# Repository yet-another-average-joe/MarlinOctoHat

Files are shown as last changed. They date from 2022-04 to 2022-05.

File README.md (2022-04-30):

# MarlinOctoHat
 
How to get rid of the Reprap Discount Full Graphics Smart Controller, and display Marlin on the OctoPi LCD.

The easiest and most efficient way to fetch the Marlin UI frames is to enable the MKS_12864OLED display in Configuration.h.

The MKS OLED 1.3" 128x64 Full Graphics Controller is based on the SSD1306, a very common OLED module. This display basically is an SPI slave. But the RaspBerry Foundation didn't think or didn't want to enable/support the SPI slave mode, which is required for emulation....

The Marlin graphics driver (a optimized u8glib fork) sends bitmaps @1Mbps. The STM32 BluePill gets these frames, reencodes them, and makes them available to the RaspBerry Pi SPI master interface. When a new frame is ready, the STM32 sends a pulse to the RasPi. The RasPi then reads the STM32 at up to 28Mbps (adjustable in the OctoPrint plugin).

As a result, the printer motherboard "sees" a SSD1306 SPI slave, and the RasPi "sees" the printer motherboard as a SPI slave peripheral ! Thanks to the STM32F103 dual SPI, and to the developpers that implemented the SPI DMA mode in the Roger's core !

The RaspBerry runs a service that overlays the Marlin UI onto the RaspBerry display using dispmanx, and an OctoPrint plugin allows for easy display customization.

This repo contains everything needed to build the hat (two PCBs and a firmware) that replaces the 12864 display. The hat is connected to the printer motherboard through the EXP1 and EXP2 connectors, and breaks out the rotary encoder, the reset button for the STM32 and the motherboard, the speaker, the "Marlin Mode" button, and a 5V screw terminal to for the RasPi and the STM32 power. It also breaks out the RasPi UART for direct connection to the motherboard (if supported...). Both 3.3V and 5V printer motherboards are supported.

The two PCBs are inexpensive, easy to populate using a decent soldering iron, and require components that every tinkerer has at hand (through hole only) : a BluePill (legit or fake), a couple of NPN tranistors and resistors, a small diode, 4 jumpers and some pinheaders and sockets (including a long RaspBerry 2x20 PC104-style pin header/socket). Everything can be easily sourced from Amazon, eBay, Ali...

The KiCad projects and the Gerber files are provided. Just order the PCBs from a manufacturer (JLCPCB, PCBWay, etc.)

Hat firmware : see https://github.com/yet-another-average-joe/MarlinOctoHat/tree/main/MarlinOctoHat_Firmware

RasPi software (service and OctoPrint plugin) :

service : https://github.com/yet-another-average-joe/OctoPrint_MarlinOSD_Service

plugin : https://github.com/yet-another-average-joe/OctoPrint_MarlinOSD_Plugin

**The SSD1306 (MKS OLED 1.3" 128x64 Full Graphics Controller) is not supported for all motherboards, even though the option is available in Configuration.h ; enabling support is not difficult, but requires sone basic knowledge about Marlin and microcontrollers ! The pins files are somewhere under Marlin/src/pins : some "#define..." to add if needed. The motherboard schematics and pinouts might be needed ; forums and dicussion groups could be helpfull !**

First, enable the "MKS OLED 1.3" 128x64 Full Graphics Controller" in Configurattion.h :

#define MKS_12864OLED

If the OLED is not supported, you will get a compile error similar to :

In file included from Marlin\src\lcd\dogm\marlinui_DOGM.cpp:42:

Marlin\src\lcd\dogm\marlinui_DOGM.cpp: In static member function 'static void MarlinUI::init_lcd()':

Marlin\src\lcd\dogm\marlinui_DOGM.h:223:48: error: 'DOGLCD_CS' was not declared in this scope; did you mean 'DOGLCD_SCK'?

You'll have to add such a block in your pins definition file :

      #elif ENABLED(MKS_12864OLED_SSD1306)
        #define DOGLCD_CS            EXP1_05_PIN
        #define DOGLCD_A0            EXP1_04_PIN
        #define DOGLCD_SCK           EXP2_09_PIN
        #define DOGLCD_MOSI          EXP2_05_PIN
        #define LCD_PINS_DC          LCD_PINS_D4
        //#define FORCE_SOFT_SPI                      // Use this if default of hardware SPI causes display problems
      #endif

You could have to figure wich microcontroller pins go to the EXP1 and EXP2 pin headers. May be done without the schematics, but easier with.

**THIS IS AN EXAMPLE !** : lines I had to add to /Marlin/src/pins/lpc1768/pins_BTT_SKR_V1_4.h for a SKR 1.4 Turbo.

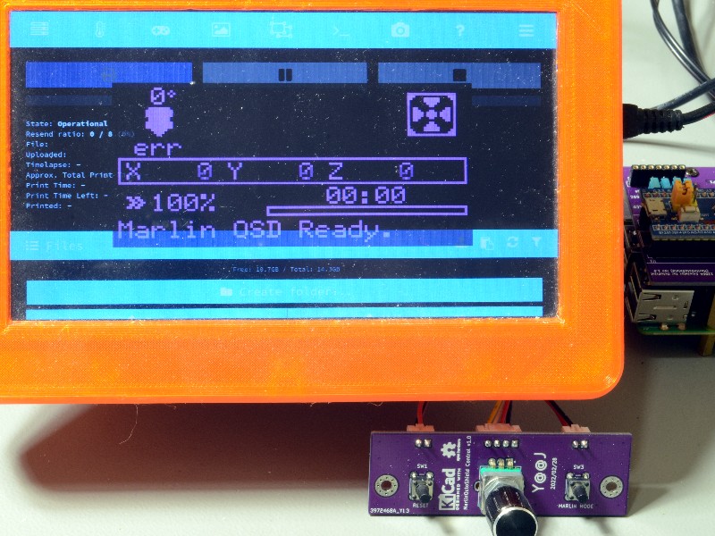
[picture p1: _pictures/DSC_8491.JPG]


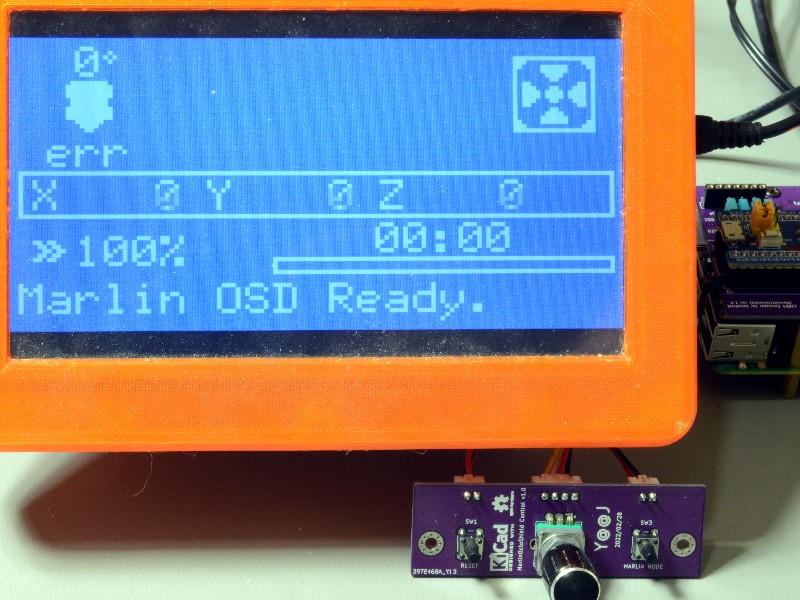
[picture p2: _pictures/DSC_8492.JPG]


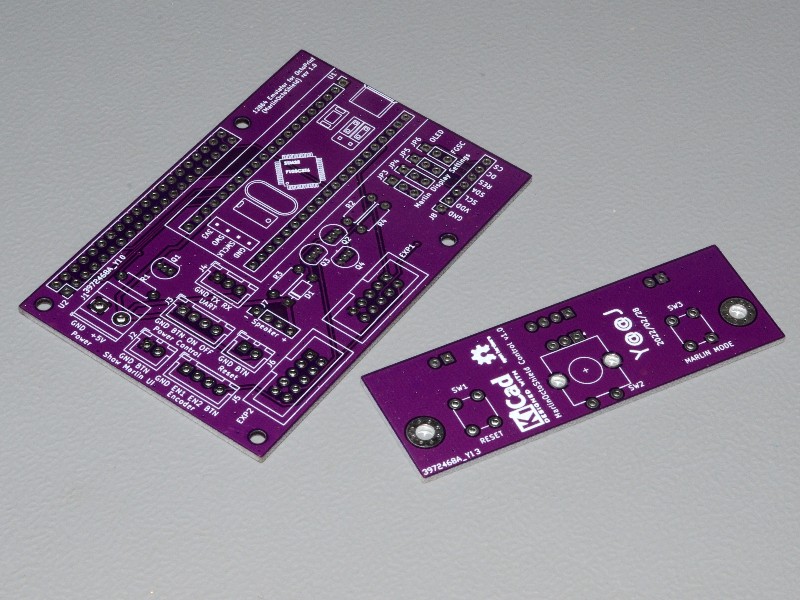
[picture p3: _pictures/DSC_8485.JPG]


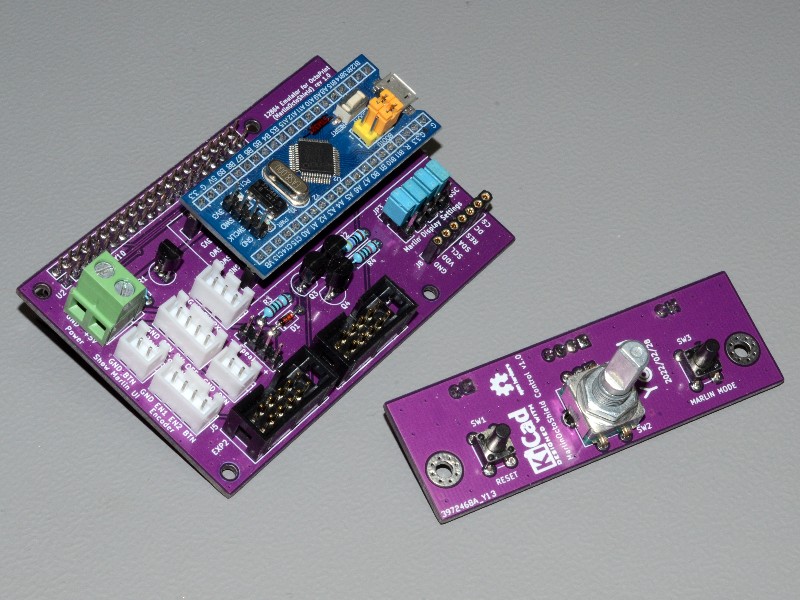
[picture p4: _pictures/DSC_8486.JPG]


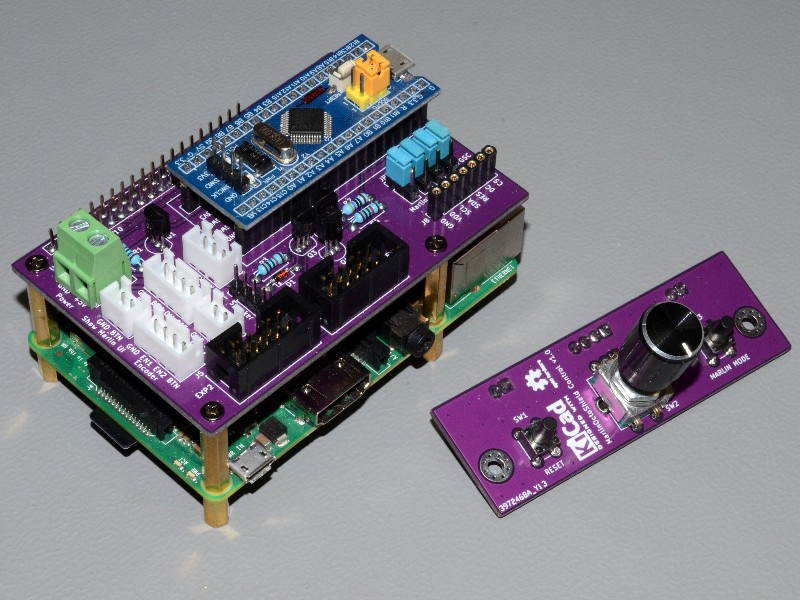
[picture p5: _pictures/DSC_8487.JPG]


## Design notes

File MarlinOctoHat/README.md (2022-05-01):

# MarlinOctoHat : hat PCB
 
The Blue Pill may be legit or "fake" : tested with ST Microeletronics STM32F103C8 and chinese CKS32F103C8T6.

**KiCad 6.0 project** :

subfolders :

- **bom** : bill of material created with "Interactive Html Bom" plugin
- **fabrication** : fabrication files created with "KiCAD JLCPCB tools" plugin

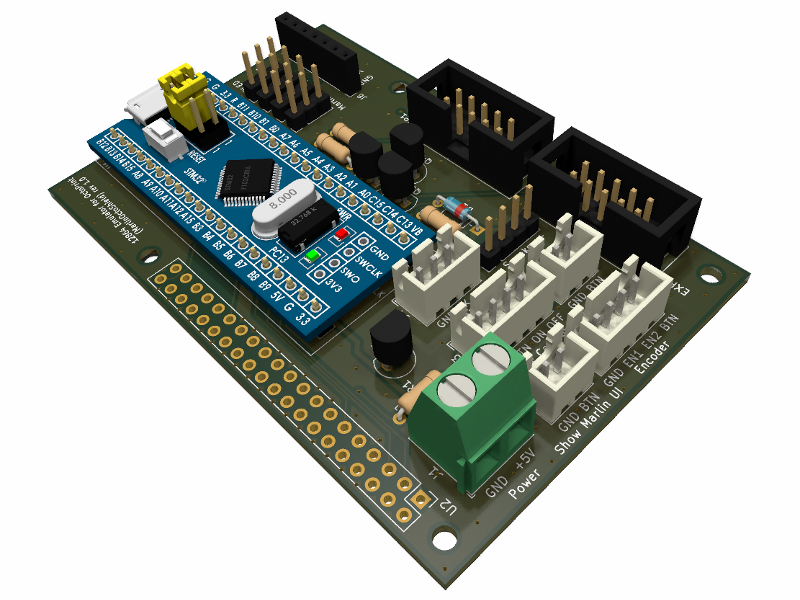
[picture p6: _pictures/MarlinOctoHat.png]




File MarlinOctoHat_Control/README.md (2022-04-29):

# MarlinOctoHat_Control : control board
 
**KiCad 6.0 project** :

subfolders :

- **bom** : bill of material created with "Interactive Html Bom" plugin
- **fabrication** : fabrication files created with "KiCAD JLCPCB tools" plugin

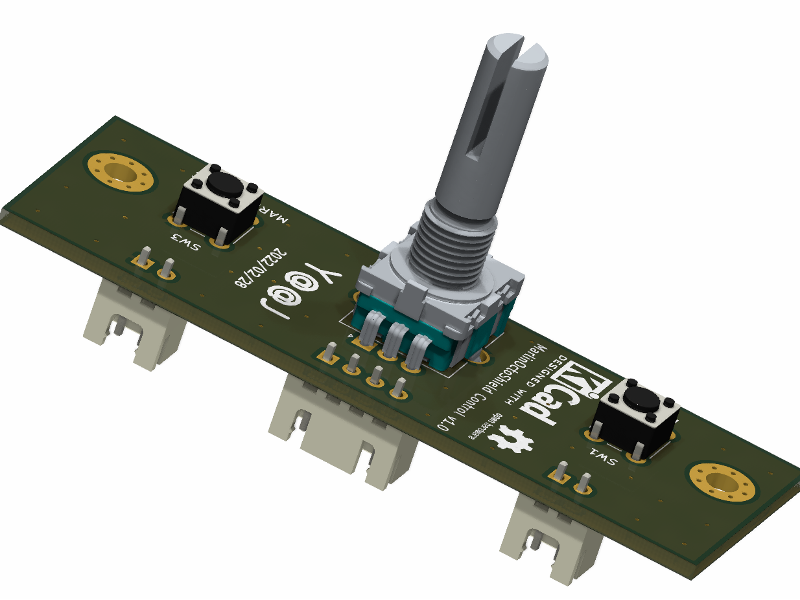
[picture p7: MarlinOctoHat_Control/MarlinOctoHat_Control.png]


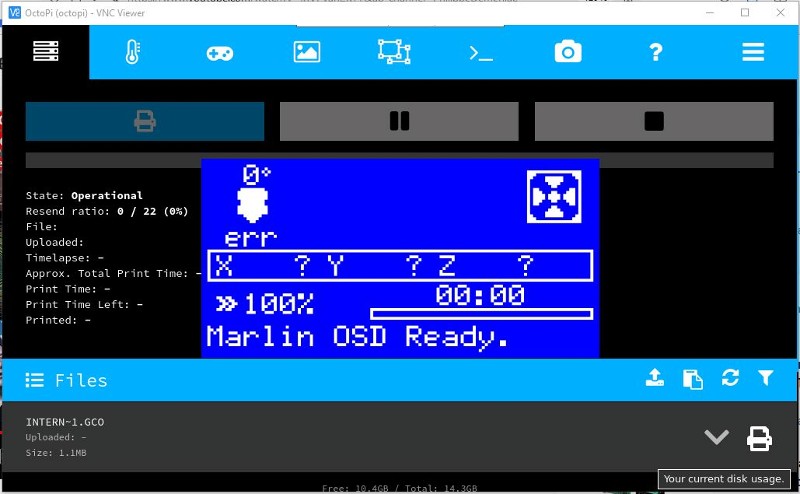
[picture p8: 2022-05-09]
_pictures/VNC_Capture_01.JPG

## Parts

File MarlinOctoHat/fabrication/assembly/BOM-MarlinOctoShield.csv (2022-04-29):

Comment | Designator | Footprint | LCSC
BC547 | Q3 | TO-92_Inline
Jumper_3_Bridged12 | JP6 | PinHeader_1x03_P2.54mm_Vertical
10k | R1 | R_Axial_DIN0207_L6.3mm_D2.5mm_P7.62mm_Horizontal
BC547 | Q4 | TO-92_Inline
MountingHole | H1 | MountingHole_2.7mm_M2.5_DIN965
MountingHole | H4 | MountingHole_2.7mm_M2.5_DIN965
Conn_01x02_Male | J2 | JST_KNOCKOFF_XH_B2B-XH-A_1x02_P2.54mm_Vertical
Jumper_2_Open | JP3 | PinHeader_1x03_P2.54mm_Vertical
Jumper_3_Bridged12 | JP4 | PinHeader_1x03_P2.54mm_Vertical
Conn_01x02_Male | J6 | JST_KNOCKOFF_XH_B2B-XH-A_1x02_P2.54mm_Vertical
Conn_01x07_Female | J8 | PinSocket_1x07_P2.54mm_Vertical
MountingHole | H2 | MountingHole_2.7mm_M2.5_DIN965
YAAJ_BluePill_Part_Like | U1 | YAAJ_BluePill_1
Conn_02x05_Odd_Even | EXP1 | IDC-Header_2x05_P2.54mm_Vertical
Conn_01x04_Male | J3 | JST_KNOCKOFF_XH_B4B-XH-A_1x04_P2.54mm_Vertical
Conn_01x03_Male | J4 | JST_KNOCKOFF_XH_B3B-XH-A_1x03_P2.54mm_Vertical
BC547 | Q2 | TO-92_Inline
Screw_Terminal_01x03 | J1 | TerminalBlock_Phoenix_MKDS-1,5-2-5.08_1x02_P5.08mm_Horizontal
1N4148 | D1 | D_DO-35_SOD27_P7.62mm_Horizontal
Jumper_3_Bridged12 | JP5 | PinHeader_1x03_P2.54mm_Vertical
MountingHole | H3 | MountingHole_2.7mm_M2.5_DIN965
10k | R4 | R_Axial_DIN0207_L6.3mm_D2.5mm_P7.62mm_Horizontal
Conn_02x05_Odd_Even | EXP2 | IDC-Header_2x05_P2.54mm_Vertical
10k | R3 | R_Axial_DIN0207_L6.3mm_D2.5mm_P7.62mm_Horizontal
Conn_01x02_Male | J7 | PinHeader_1x04_P2.54mm_Vertical
Conn_01x04_Male | J5 | JST_KNOCKOFF_XH_B4B-XH-A_1x04_P2.54mm_Vertical
YAAJ_Raspberry_Pi_2_3_GPIO | U2 | PinHeader_2x20_P2.54mm_Vertical
470 | R2 | R_Axial_DIN0207_L6.3mm_D2.5mm_P7.62mm_Horizontal
BC547 | Q1 | TO-92_Inline

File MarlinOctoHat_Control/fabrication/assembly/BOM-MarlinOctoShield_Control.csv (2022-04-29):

Comment | Designator | Footprint | LCSC
SW_Push | SW1 | SW_PUSH_6mm_H4.3mm_Orig_Center
MountingHole | H2 | MountingHole_3.2mm_M3_Pad_Via
MountingHole | H1 | MountingHole_3.2mm_M3_Pad_Via
RotaryEncoder_Switch | SW2 | RotaryEncoder_Alps_EC11E-Switch_Vertical_H20mm_CircularMountingHoles_Orig_Center
3 | SW3 | SW_PUSH_6mm_H4.3mm_Orig_Center
Conn_01x02_Male | J3 | JST_KNOCKOFF_XH_B2B-XH-A_1x02_P2.54mm_Vertical
Conn_01x04_Male | J2 | JST_KNOCKOFF_XH_B4B-XH-A_1x04_P2.54mm_Vertical
Conn_01x02_Male | J1 | JST_KNOCKOFF_XH_B2B-XH-A_1x02_P2.54mm_Vertical

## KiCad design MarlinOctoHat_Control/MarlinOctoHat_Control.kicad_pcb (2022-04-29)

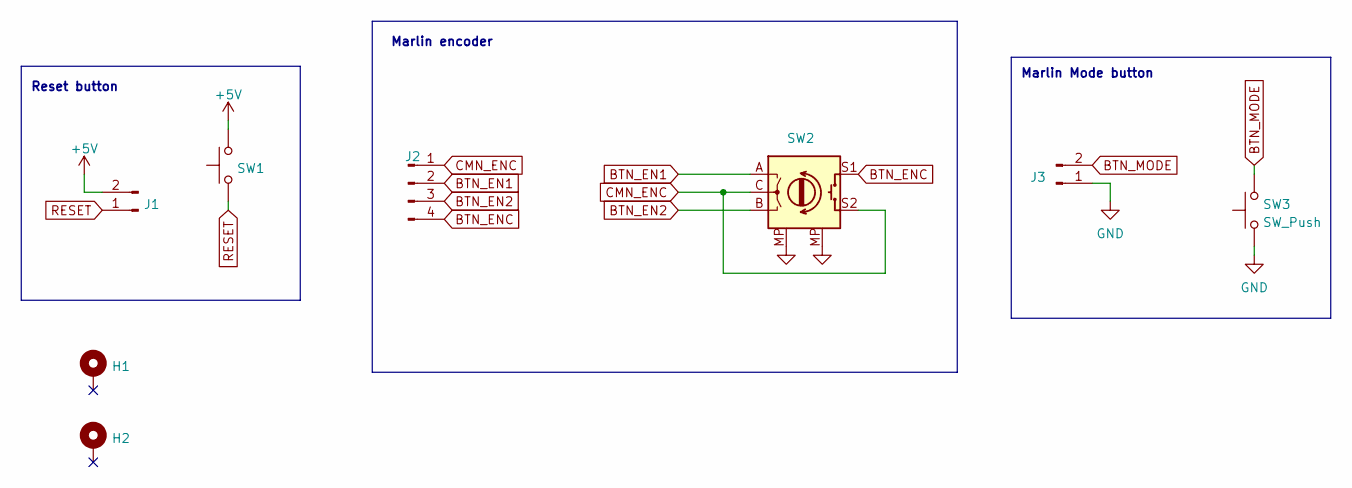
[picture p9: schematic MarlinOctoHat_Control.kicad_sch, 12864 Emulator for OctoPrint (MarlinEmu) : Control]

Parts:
H1, H2: MountingHole; MountingHole_3.2mm_M3_Pad_Via
J1, J3: Conn_01x02_Male; JST_KNOCKOFF_XH_B2B-XH-A_1x02_P2.54mm_Vertical
J2: Conn_01x04_Male; JST_KNOCKOFF_XH_B4B-XH-A_1x04_P2.54mm_Vertical
SW1, SW3: SW_Push; SW_PUSH_6mm_H4.3mm_Orig_Center
SW2: RotaryEncoder_Switch; RotaryEncoder_Alps_EC11E-Switch_Vertical_H20mm_CircularMoun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

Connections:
+5V: J1.2, SW1.2
BTN_EN1: J2.2, SW2.A
BTN_EN2: J2.3, SW2.B
BTN_ENC: J2.4, SW2.S1
BTN_MODE: J3.2, SW3.2
CMN_ENC: J2.1, SW2.C, SW2.S2
GND: J3.1, SW2.MP, SW3.1
RESET: J1.1, SW1.1

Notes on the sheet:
Marlin Mode button
Reset button
Marlin encoder

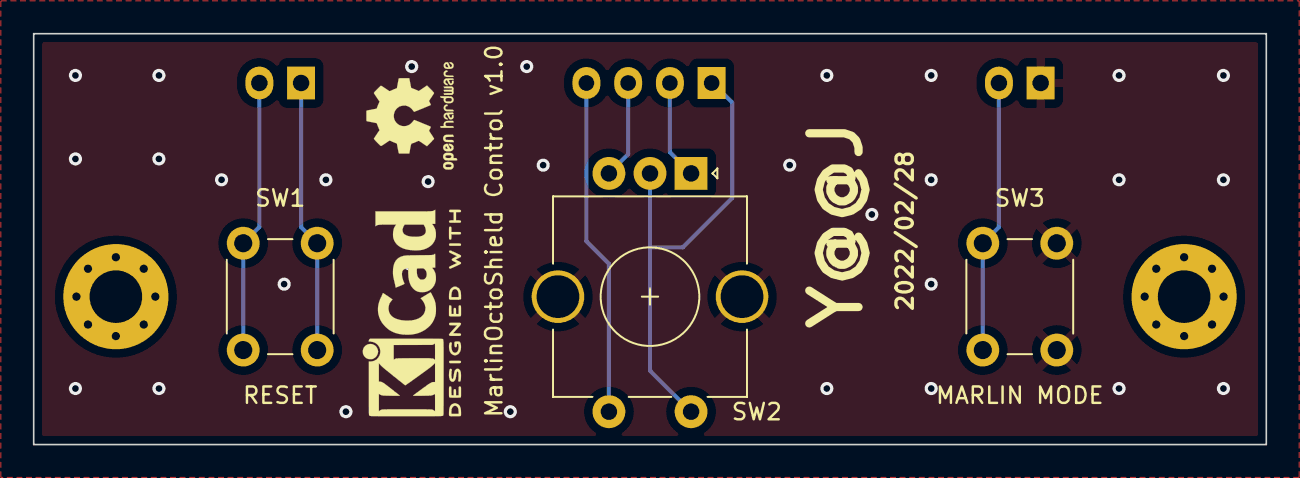
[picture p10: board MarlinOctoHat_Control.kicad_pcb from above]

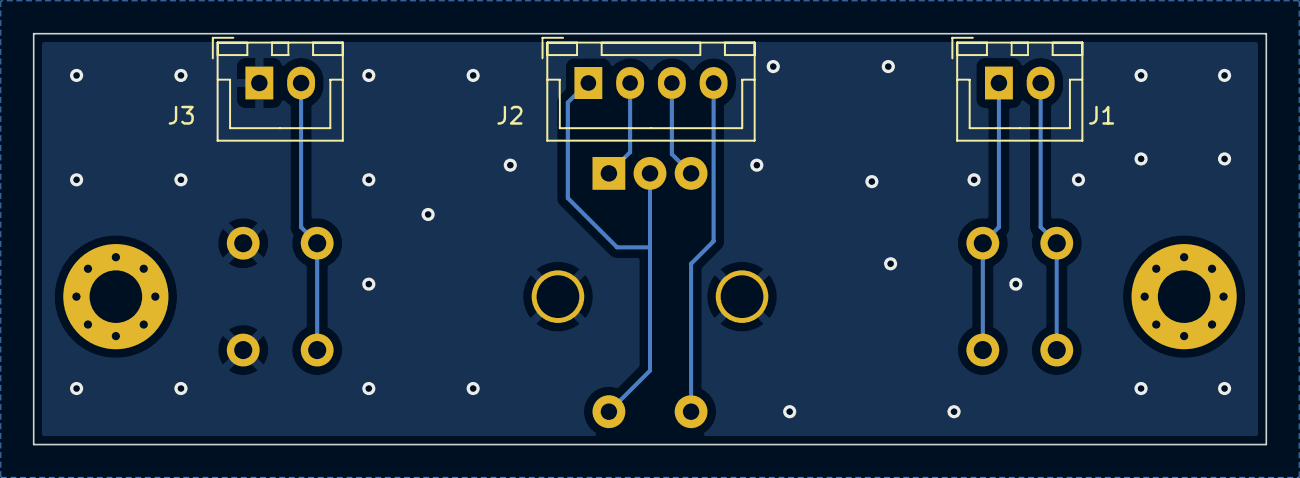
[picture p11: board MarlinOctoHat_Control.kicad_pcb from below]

Board: 2 copper layers, 75.0 x 25.0 mm, 8 parts (3 on the bottom side), 8 nets.

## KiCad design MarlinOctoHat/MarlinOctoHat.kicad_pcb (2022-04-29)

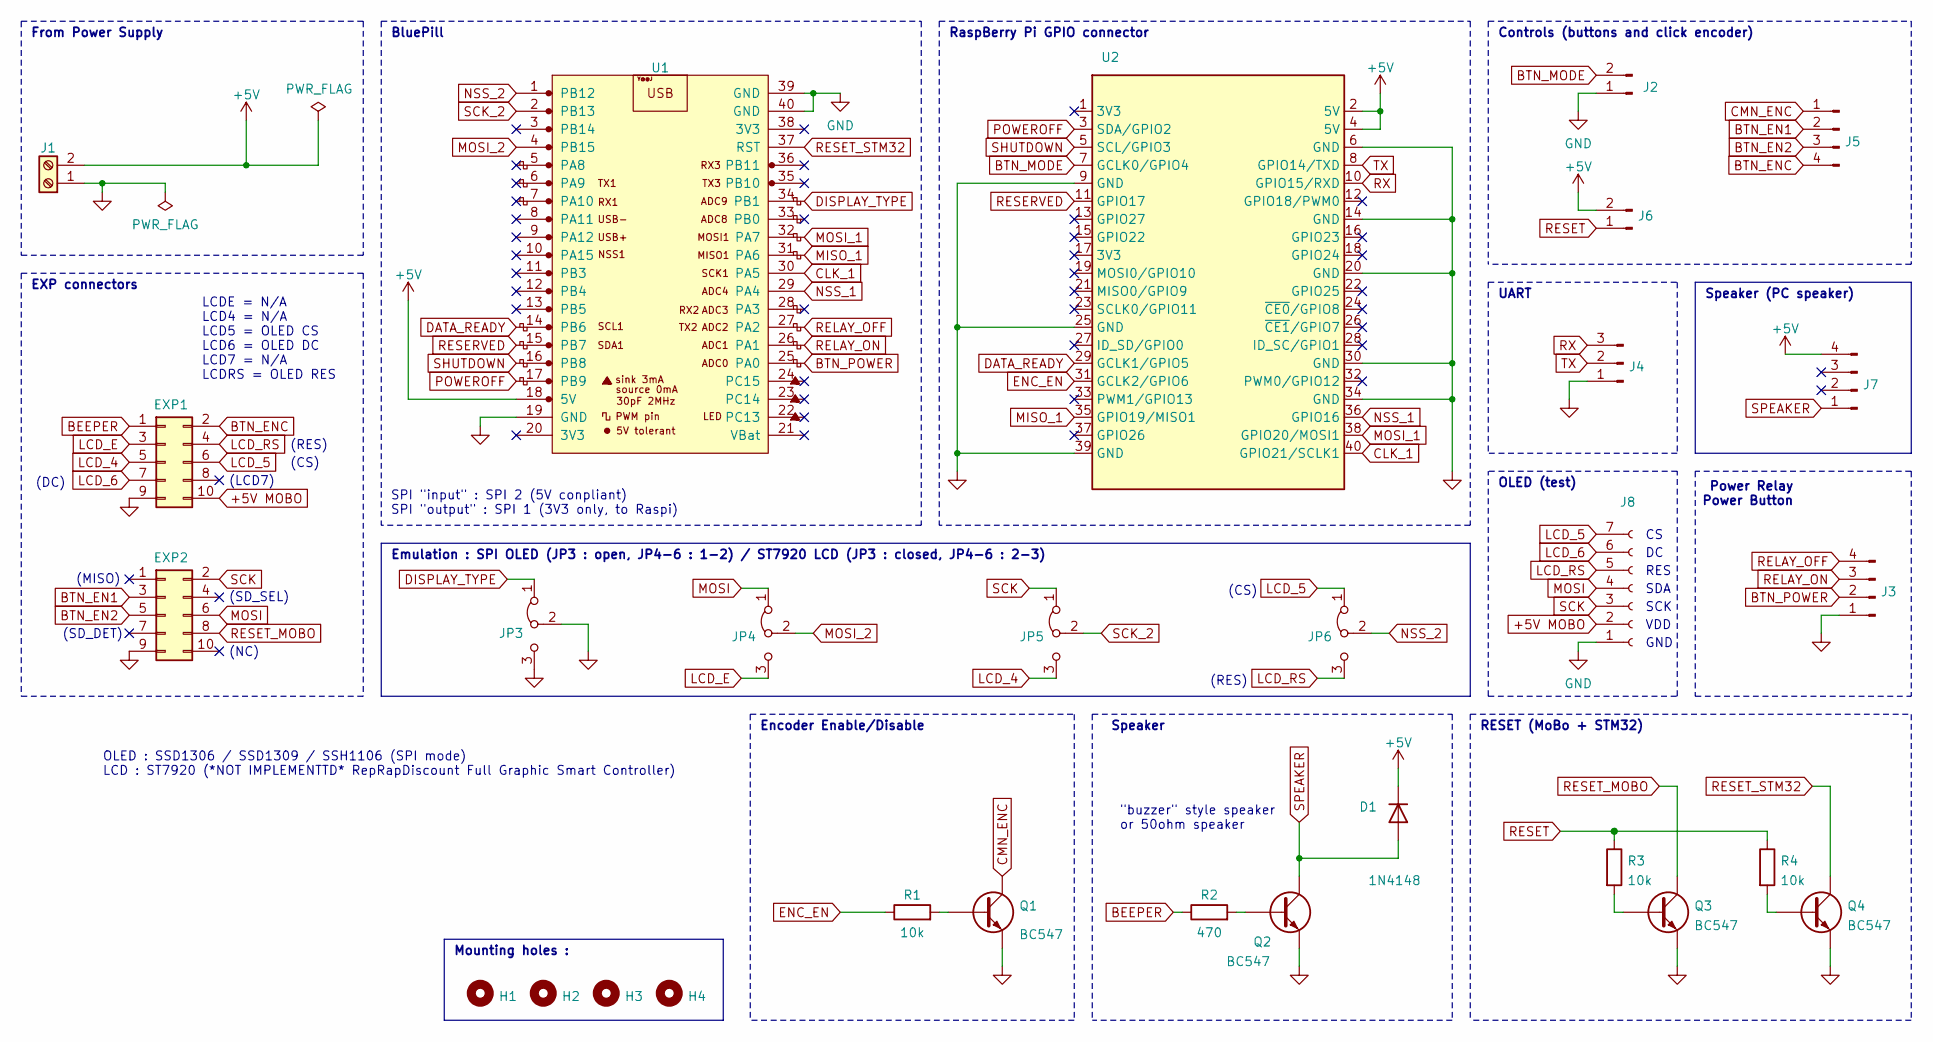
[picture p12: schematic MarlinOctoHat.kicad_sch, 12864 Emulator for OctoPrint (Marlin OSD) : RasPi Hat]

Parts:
D1: 1N4148; D_DO-35_SOD27_P7.62mm_Horizontal
EXP1, EXP2: Conn_02x05_Odd_Even; IDC-Header_2x05_P2.54mm_Vertical
H1, H2, H3, H4: MountingHole; MountingHole_2.7mm_M2.5_DIN965
J1: Screw_Terminal_01x03; TerminalBlock_Phoenix_MKDS-1,5-2-5.08_1x02_P5.08mm_Horizont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
J2, J6: Conn_01x02_Male; JST_KNOCKOFF_XH_B2B-XH-A_1x02_P2.54mm_Vertical
J3, J5: Conn_01x04_Male; JST_KNOCKOFF_XH_B4B-XH-A_1x04_P2.54mm_Vertical
J4: Conn_01x03_Male; JST_KNOCKOFF_XH_B3B-XH-A_1x03_P2.54mm_Vertical
J7: Conn_01x04_Male; PinHeader_1x04_P2.54mm_Vertical
J8: Conn_01x07_Female; PinSocket_1x07_P2.54mm_Vertical
JP3: Jumper_2_Open; PinHeader_1x03_P2.54mm_Vertical
JP4, JP5, JP6: Jumper_3_Bridged12; PinHeader_1x03_P2.54mm_Vertical
Q1, Q2, Q3, Q4: BC547; TO-92_Inline
R1, R3, R4: 10k; R_Axial_DIN0207_L6.3mm_D2.5mm_P7.62mm_Horizontal
R2: 470; R_Axial_DIN0207_L6.3mm_D2.5mm_P7.62mm_Horizontal
U1: YAAJ_BluePill_Part_Like; YAAJ_BluePill_1
U2: YAAJ_Raspberry_Pi_2_3_GPIO; PinHeader_2x20_P2.54mm_Vertical

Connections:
+5V: D1.1 (K), J1.2, J6.2, J7.4, U1.18 (5V), U2.2 (5V), U2.4 (5V)
+5V MOBO: EXP1.10, J8.2
BEEPER: EXP1.1, R2.1
BTN_EN1: EXP2.3, J5.2
BTN_EN2: EXP2.5, J5.3
BTN_ENC: EXP1.2, J5.4
BTN_MODE: J2.2, U2.7 (GCLK0/GPIO4)
BTN_POWER: J3.2, U1.25 (PA0)
CLK_1: U1.30 (PA5), U2.40 (GPIO21/SCLK1)
CMN_ENC: J5.1, Q1.1 (C)
DATA_READY: U1.14 (PB6), U2.29 (GCLK1/GPIO5)
DISPLAY_TYPE: JP3.1 (A), U1.34 (PB1)
ENC_EN: R1.1, U2.31 (GCLK2/GPIO6)
GND: EXP1.9, EXP2.9, J1.1, J2.1, J3.1, J4.1, J8.1, JP3.2 (C), JP3.3 (B), Q1.3 (E), Q2.3 (E), Q3.3 (E), Q4.3 (E), U1.19 (GND), U1.39 (GND), U1.40 (GND), U2.6 (GND), U2.9 (GND), U2.14 (GND), U2.20 (GND), U2.25 (GND), U2.30 (GND), U2.34 (GND), U2.39 (GND)
LCD_4: EXP1.5, JP5.3 (B)
LCD_5: EXP1.6, J8.7, JP6.1 (A)
LCD_6: EXP1.7, J8.6
LCD_E: EXP1.3, JP4.3 (B)
LCD_RS: EXP1.4, J8.5, JP6.3 (B)
MISO_1: U1.31 (PA6), U2.35 (GPIO19/MISO1)
MOSI: EXP2.6, J8.4, JP4.1 (A)
MOSI_1: U1.32 (PA7), U2.38 (GPIO20/MOSI1)
MOSI_2: JP4.2 (C), U1.4 (PB15)
NSS_1: U1.29 (PA4), U2.36 (GPIO16)
NSS_2: JP6.2 (C), U1.1 (PB12)
unnamed: Q1.2 (B), R1.2
unnamed: Q2.2 (B), R2.2
unnamed: Q3.2 (B), R3.2
unnamed: Q4.2 (B), R4.2
POWEROFF: U1.17 (PB9), U2.3 (SDA/GPIO2)
RELAY_OFF: J3.4, U1.27 (PA2)
RELAY_ON: J3.3, U1.26 (PA1)
RESERVED: U1.15 (PB7), U2.11 (GPIO17)
RESET: J6.1, R3.1, R4.1
RESET_MOBO: EXP2.8, Q3.1 (C)
RESET_STM32: Q4.1 (C), U1.37 (RST)
RX: J4.3, U2.10 (GPIO15/RXD)
SCK: EXP2.2, J8.3, JP5.1 (A)
SCK_2: JP5.2 (C), U1.2 (PB13)
SHUTDOWN: U1.16 (PB8), U2.5 (SCL/GPIO3)
SPEAKER: D1.2 (A), J7.1, Q2.1 (C)
TX: J4.2, U2.8 (GPIO14/TXD)

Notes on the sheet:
OLED (test)
SCK
(LCD7)
OLED : SSD1306 / SSD1309 / SSH1106 (SPI mode) LCD : ST7920 (*NOT IMPLEMENTTD* RepRapDiscount Full Graphic Smart Controller)
RaspBerry Pi GPIO connector
Emulation : SPI OLED (JP3 : open, JP4-6 : 1-2) / ST7920 LCD (JP3 : closed, JP4-6 : 2-3)
(NC)
(CS)
GND
UART
BluePill
(SD_SEL)
RESET (MoBo + STM32)
(DC)
From Power Supply
Speaker (PC speaker)
Mounting holes :
(SD_DET)
RES
VDD
SDA
SPI "input" : SPI 2 (5V conpliant) SPI "output" : SPI 1 (3V3 only, to Raspi)
"buzzer" style speaker or 50ohm speaker
(RES)
Speaker
Encoder Enable/Disable
EXP connectors
Power Relay Power Button
(MISO)
Controls (buttons and click encoder)
LCDE = N/A LCD4 = N/A LCD5 = OLED CS LCD6 = OLED DC LCD7 = N/A LCDRS = OLED RES

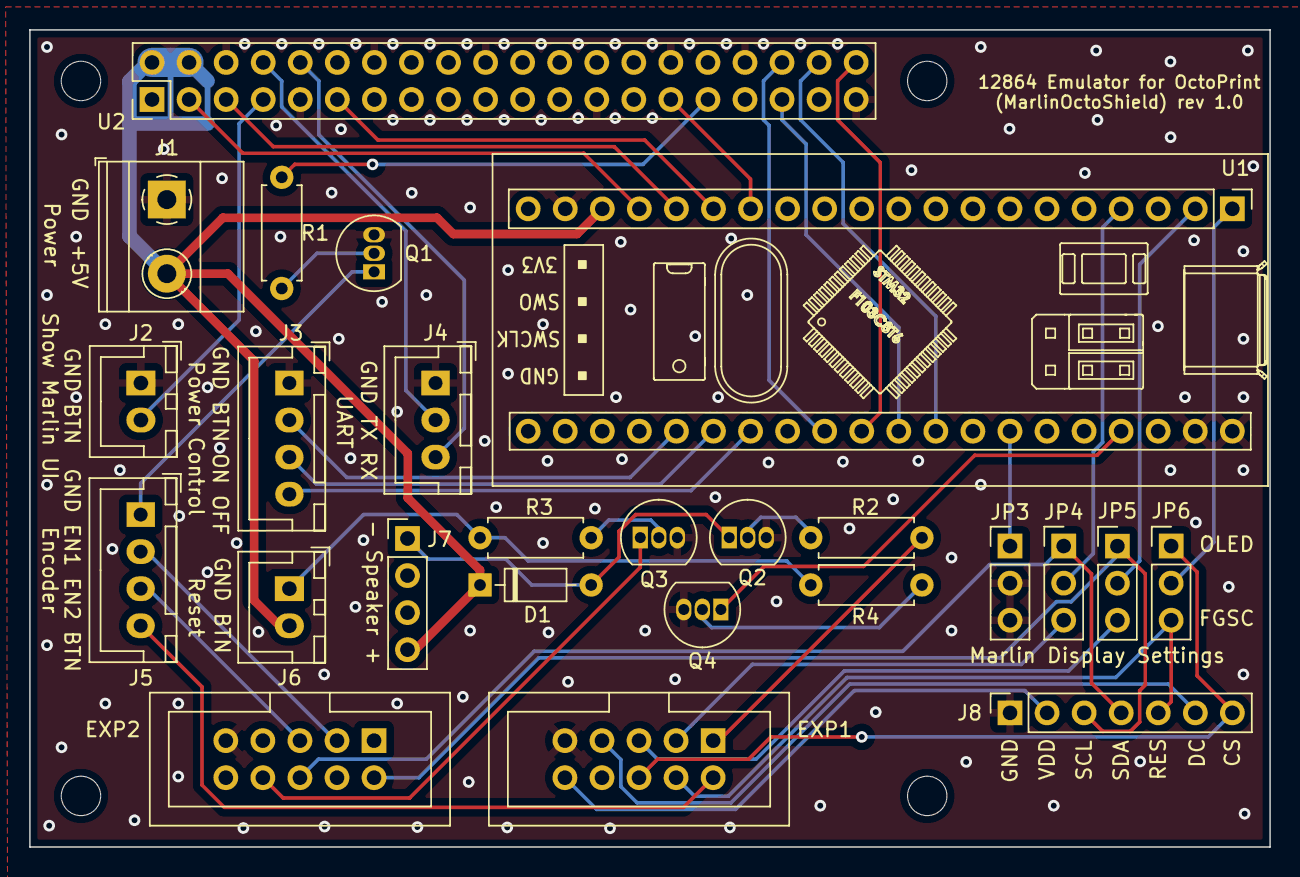
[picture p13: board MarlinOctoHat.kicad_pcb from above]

Board: 2 copper layers, 85.0 x 56.0 mm, 30 parts (1 on the bottom side), 42 nets.

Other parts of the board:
LOGO1: OSHW-Logo_7.5x8mm_SilkScreen

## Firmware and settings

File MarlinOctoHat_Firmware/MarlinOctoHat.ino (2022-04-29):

/*
 Name:        MarlinOctoHat.ino
 Created:    31/08/2021 11:16:18
 Author:    Y@@J
    TODO : pins PB10/PB11 = input for emulator selection OLED SSD1306 / OLED SSD1309 / OLED SSH1106 / LCD ST7920
            DISPLAY_TYPE : PB1
    TODO : power management
            support for monostable relay throught PIN_RELAY_ON
    /////////////////////////////////////////////////////////////////////////////////////
    SPI Slave Sniffer for the SSD1306/SSD1309/SSH1106 OLED ; for marlin UI, u8glib
    tested Ok with SPI SSD1309 OLED and Marlin v2.0.x on genuine and fake STM32F103C6 ("BluePill")
    /////////////////////////////////////////////////////////////////////////////////////
    thread on stm32duino.com, and special thanks for the help about SPI DMA tranfers ! :
    https://www.stm32duino.com/viewtopic.php?t=825
    SSD1306 datasheet :
    https://cdn-shop.adafruit.com/datasheets/SSD1306.pdf
    SPI data :
    1 SPI frame = 8 pages
    1 page = 8lines/128 pixels, vertical macropixels
    1 page : 3 command bytes + 128 bytes (= 8 lines on the display)
    1 command byte = 0x10 0x00 0XBn , n = page # (0...7)
    total : 8 pages ; 8 * 131 = 1048 bytes, CLK @ 1MHz
    /////////////////////////////////////////////////////////////////////////////////////
    // OLED wirings
        SSD1306-9        SPI
        SH1106
        SCL                SCLK
        SDA                MOSI
        RES                N/A
        DC                N/A
        SS                SS
    SS : LOW for pages, including commands ; HIGH between pages and between frames
    DC : LOW for commands only
    // BluePill / RaspBerry Pi wirings
                                              ----------
                        (LCD_5)  [NSS2] PB12 |            | GND
                        (SCK)    [SCK2] PB13 |            | GND
                                        PB14 |            | 3V3
                        (MOSI)  [MOSI2] PB15 |            | RESET
                                         PA8 |            | PB11 -> GPIO2  (AUX4)
                                         PA9 |            | PB10 -> GPIO3  (AUX3)
                                        PA10 |            | PB1
                                        PA11 |            | PB0
                                        PA12 |            | PA7  [MOSI1] -> GPIO20 (SPI1 MOSI)
                                        PA15 |            | PA6  [MISO1] -> GPIO19 (SPI1 MISO)
                             (LCD_E)    PB3  |            | PA5  [SCK1]  -> GPIO21 (SPI1 SCLK)
                             (LCD_4)    PB4  |            | PA4  [NSS1]  -> GPIO16 (SPI1 CS0)
                             (LCD_7)    PB5  |            | PA3
        GPIO5  <- DATA_READY            PB6  |            | PA2  PIN_RELAY_OFF
        GPIO17 <- PIN_SOFT_SHUTDOWN     PB7  |            | PA1  PIN_RELAY_ON
        GPIO3  <- PIN_HARD_SHUTDOWN     PB8  |            | PA0  PIN_BTN_POWER
        GPIO2  <- PIN_POWEROFF          PB9  |            | PC15
                                         5V  |            | PC14
                                        GND  |            | PC13
                                        3V3  |            | VBAT
                                             |            |
                                              ----------
    LCD_E, LCD_4, LCD_7 : variant with ST7920 emulator (not implemented)
    SPI2 : SPI "input" (MOSI), from printer motherboard
    ---------------------------------------------------
        STM32 Pins : 5V tolerant
            MoBo        OLED    BluePill
            XP1_5        CS        PB12    PIN_SS_2
            XP2-9        SCL       PB13    PIN_SCK_2
                         N/C       PB14
            EXP2-5       SDA       PB15    PIN_MOSI_2
    SPI1 :    SPI "output" (MISO), to RasPi
    -------------------------------------
        STM32 Pins : /!\ NOT 5V TOLERANT /!\
            PIN_READY : high for READY_PULSE_DURATION ms when a new bitmap is available
                        tells the RasPi it's time to get data and refresh display
                        drastically reduces RasPi CPU usage
                    BluePill            PasPi
             PA7    PIN_MOSI1            [38]    GPIO20    MOSI1
            (PA6    PIN_MISO1            [35]    GPIO19    MISO1)
             PA5    PIN_SCK1             [40]    GPIO21    SCK1
             PA4    PIN_NSS1             [36]    GPIO16    NSS1
             PB6    PIN_READY            [29]    GPIO5     data ready to send
             PB7    PIN_SOFT_SHUTDOWN    [11]    GPIO17    output, default = LOW, HIGH = short press -> OctoPrint Shutdown
             PB8    PIN_HARD_SHUTDOWN    [5]     GPIO3     output, default = LOW, HIGH triggered by PIN_BTN_POWER long press -> OS Shutdown
             PB9    PIN_POWEROFF         [3]     GPIO2     input, interrupt
             PA0    PIN_BTN_POWER        [33]    GPIO13    input, pullup,    interrupt, sends 1 sec LOW pulse to PIN_HARD_SHUTDOWN
             PA1    PIN_RELAY_ON         [32]    GPIO12    output, default = LOW, HIGH for 1 sec at boot
             PA2    PIN_RELAY_OFF        [31]    GPIO6     output, default = LOW, HIGH triggerd by PIN_POWEROFF

*/
lkjhsqdgfklhjgbqskdhjgbksdqjhgdksjhkqgqsdkjfhgqsdf
#include <SPI.h>
//#include "Bitmaps.h"

//#define __SERIAL_DEBUG // costs 2328 bytes

//////////////////////////////////////////////////////////////////////////////////////////////////////////////
// pins : pullups ? pulldowns ?

// SPI_1 : input (MOSI), OLED sniffing ; /!\ *NOT* 5V tolerant
// SPI_2 : output (MISO), to RaspBerry Pi
// pins are set by the library

#define READY_PULSE_DURATION    1        // 1ms

#define PIN_READY        PB6

//#define PIN_HARD_SHUTDOWN    PB8        // to RasPi Shutdown pin (5 / GPIO3)
//#define PIN_POWEROFF         PB9        // from RasPi PowerOff pin (2 / GPIO2)
#define PIN_BTN_POWER        PA0        // Power button
#define PIN_RELAY_ON         PA1        // to PSU module ; ON bistable coil
#define PIN_RELAY_OFF        PA2        // to PSU module ; OFF bistable coil
#define PIN_SOFT_SHUTDOWN    PB7        // to RasPi (11 / GPIO17)

#define LONG_PRESS_TIME            1500    // milliseconds
#define DEBOUNCE_TIME                25    // milliseconds
#define HARD_SHUTDOWN_PULSE         500    // 100ms debounce by default on RasPi ; min pulse width 210ms (measured)
#define SOFT_SHUTDOWN_PULSE         500    // milliseconds
#define RELAY_PULSE                 500    // milliesconds ; Schrack RT314F12 : min 30 ms

//////////////////////////////////////////////////////////////////////////////////////////////////////////////
// OLED    data

// data (SSD1306/SSD1309) : 1 frame = 8 pages, 1 page = 3 command bytes + 128 bytes, 1 page = 8 graphic lines
#define OLED_PAGE_COUNT          8
#define    OLED_LINES_PER_PAGE   8
#define OLED_CMD_SIZE            3
#define OLED_PAGE_SIZE           128
#define OLED_SPI_PAGE_SIZE       (OLED_CMD_SIZE + OLED_PAGE_SIZE)        // 1048
#define OLED_SPI_FRAME_SIZE      (OLED_PAGE_COUNT * OLED_SPI_PAGE_SIZE)  // 1024

// bmpOled with vertical 8bit monochrome macropixels...
volatile uint8_t bmpOled[OLED_PAGE_COUNT][OLED_PAGE_SIZE] = { 0 };

// converts bmpOled to horizontal 8bit monochrome macropixels
// will be used as Tx buffer for SPI_1
// allways keeps the last captured screen until a new one arrives
volatile uint8_t bmpOut[OLED_PAGE_COUNT * OLED_PAGE_SIZE] = { 0 };

//////////////////////////////////////////////////////////////////////////////////////////////////////////////
// SPI 1&2 : DMA channels

#define SPI_1_TX_DMA_CH        DMA_CH3
#define SPI_2_RX_DMA_CH        DMA_CH4

//////////////////////////////////////////////////////////////////////////////////////////////////////////////
// SPI_2  : MOSI (Rx) only

SPIClass SPI_2(2);

#define PIN_NSS_2    PB12

volatile uint8_t SPI_2_Rx_Buffer[OLED_SPI_FRAME_SIZE] = { 0 };
volatile bool SPI_2_DMA_transfer_complete = false;
volatile bool SPI_2_DMA_error = false;

// DMA tube configuration for SPI2 Rx
dma_tube_config SPI_2_DMA_RxTubeCfg =
{
    &SPI2->regs->DR,           // Source of data
    DMA_SIZE_8BITS,            // Source transfer size
    &SPI_2_Rx_Buffer,          // Destination of data
    DMA_SIZE_8BITS,            // Destination transfer size
    sizeof(SPI_2_Rx_Buffer),   // Number of bytes to receive
                               // Flags :
    DMA_CFG_DST_INC |          // auto increment destination address
    DMA_CFG_CIRC |             // circular buffer
    DMA_CFG_CMPLT_IE |         // set tube full IRQ
    DMA_CFG_ERR_IE |           // want messages in the DMA irq
    DMA_CCR_PL_VERY_HIGH,      // very high priority
    0,                         // reserved
    DMA_REQ_SRC_SPI2_RX        // Hardware DMA request source
};

void setup_SPI_2();
void setup_SPI_2_DMA();
void SPI_2_DMA_IRQ();

//////////////////////////////////////////////////////////////////////////////////////////////////////////////
// SPI_1 : MISO (Tx) only

#define SPI_1        SPI

// DMA tube configuration for SPI1 Tx ; data = bmpOut
dma_tube_config SPI_1_DMA_TxTubeCfg =
{
    bmpOut,                     // Data source
    DMA_SIZE_8BITS,             // Source transfer size
    &SPI1->regs->DR,            // Destination of data
    DMA_SIZE_8BITS,             // Destination transfer size
    sizeof(bmpOut),             // Number of bytes to transfer
                                // Flags :
    DMA_CFG_SRC_INC |           // auto increment source address
    DMA_CFG_CIRC |              // circular buffer
    DMA_CFG_CMPLT_IE |          // set tube full IRQ
    DMA_CFG_ERR_IE |            // want messages in the DMA irq
    DMA_CCR_PL_VERY_HIGH,       // very high priority
    0,                          // reserved
    DMA_REQ_SRC_SPI1_TX         // Hardware DMA request source
};

void setup_SPI_1();
void setup_SPI_1_DMA();

//////////////////////////////////////////////////////////////////////////////////////////////////////////////
// ISR : NSS_2
// RISING : if not a payload frame, reset SPI + DMA
// pages begin with 0x10 0x00 0xB6 nn, 0 <= n <= 7)

void ISR_NSS_2()
{
    volatile uint8_t* p = SPI_2_Rx_Buffer;

    // keep pages only : 0x10 0x00 0xBn (0 <= n < 8)
    if ((*p++ != 0x10) || (*p++ != 0x00) || ((*p++ & 0xF0) != 0xB0) || ((*p & 0x0F) > 7)) // not a page or not in sync
    {
        // reset
        dma_disable(DMA1, SPI_2_RX_DMA_CH);
        dma_tube_cfg(DMA1, SPI_2_RX_DMA_CH, &SPI_2_DMA_RxTubeCfg);
        dma_enable(DMA1, SPI_2_RX_DMA_CH);
    }
}

//////////////////////////////////////////////////////////////////////////////////////////////////////////////
// ISR : PIN_POWEROFF
// "poweroff" from RasPi

bool flagPowerOff = false;

void ISR_POWEROFF()
{
    flagPowerOff = true;
}

//////////////////////////////////////////////////////////////////////////////////////////////////////////////
// function : "Arduino" setup()

void setup()
{
#ifdef __SERIAL_DEBUG
    Serial.begin(115200);
#endif

//    pinMode(PIN_HARD_SHUTDOWN, OUTPUT);
//    digitalWrite(PIN_HARD_SHUTDOWN, HIGH);
    pinMode(PIN_SOFT_SHUTDOWN, OUTPUT);
    digitalWrite(PIN_SOFT_SHUTDOWN, HIGH);

    pinMode(LED_BUILTIN, OUTPUT); // blinks when display is updated

    pinMode(PIN_READY, OUTPUT);
    digitalWrite(PIN_READY, LOW);
    pinMode(PIN_NSS_2, INPUT);    // needed ?

    //pinMode(PIN_POWEROFF, INPUT);
    pinMode(PIN_BTN_POWER, INPUT_PULLUP);
    pinMode(PIN_RELAY_ON, OUTPUT);
    pinMode(PIN_RELAY_OFF, OUTPUT);

    // turn bistable relay on
    digitalWrite(PIN_RELAY_OFF, LOW);
    digitalWrite(PIN_RELAY_ON, HIGH);
    delay(RELAY_PULSE); // bistable relay pulse
    digitalWrite(PIN_RELAY_ON, LOW);

    attachInterrupt(digitalPinToInterrupt(PIN_NSS_2), ISR_NSS_2, RISING);
    //attachInterrupt(digitalPinToInterrupt(PIN_POWEROFF), ISR_POWEROFF, FALLING);

    setup_SPI_1();
    setup_SPI_1_DMA();
    setup_SPI_2();
    setup_SPI_2_DMA();
}

//////////////////////////////////////////////////////////////////////////////////////////////////////////////
// function : "Arduino" loop()

void loop()
{
    if (SPI_2_DMA_transfer_complete && stripCmdBytes())
    {
        bmpOledToBmpOut();
        SPI_2_DMA_transfer_complete = false; // reset flag

        // tells the RasPi new bitmap is ready : 1ms pulse
        // and blinks buitibn LED
        digitalWrite(LED_BUILTIN, LOW);
        digitalWrite(PIN_READY, HIGH);
        delay(READY_PULSE_DURATION);
        digitalWrite(PIN_READY, LOW);
        digitalWrite(LED_BUILTIN, HIGH);
    }

    if (flagPowerOff)
    {
#ifdef __SERIAL_DEBUG
        Serial.println("POWER OFF");
#endif
        //detachInterrupt(PIN_POWEROFF); // 2 falling edges ; ignore the second one
        //digitalWrite(PIN_RELAY_OFF, HIGH);
        //flagPowerOff = false; // otherwise : will be called until power is off
        // no further processing : power is now off...
    }

    // see https://myhomethings.eu/en/arduino-long-short-button-press/
    static uint32 holdingTime;
    static uint32 prevHoldingTime;
    static uint32 firstButtonPressTime;
    static uint32 btnState;
    static uint32 prevBtnState = HIGH;
    static bool done = false;
    //digitalWrite(PIN_HARD_SHUTDOWN, digitalRead(PIN_BTN_POWER));
    digitalWrite(PIN_SOFT_SHUTDOWN, digitalRead(PIN_BTN_POWER));
/*
    btnState = digitalRead(PIN_BTN_POWER);

    if (btnState == LOW && prevBtnState == HIGH && (millis() - firstButtonPressTime) > DEBOUNCE_TIME)
        firstButtonPressTime = millis();

    holdingTime = (millis() - firstButtonPressTime);

    if (holdingTime > DEBOUNCE_TIME)
    {
        if (btnState == LOW && holdingTime > prevHoldingTime)
        {
            if (holdingTime > LONG_PRESS_TIME && !done)
            {
#ifdef __SERIAL_DEBUG
                Serial.println("LONG PRESS");
                //delay(HARD_SHUTDOWN_PULSE);
                digitalWrite(PIN_HARD_SHUTDOWN, LOW);
                delay(HARD_SHUTDOWN_PULSE);
                digitalWrite(PIN_HARD_SHUTDOWN, HIGH);
#else
                digitalWrite(PIN_HARD_SHUTDOWN, LOW);
                delay(HARD_SHUTDOWN_PULSE);
                digitalWrite(PIN_HARD_SHUTDOWN, HIGH);
#endif
                done = true;
            }
        }

        if (btnState == HIGH && prevBtnState == LOW)
        {
            done = false;

            if (holdingTime <= LONG_PRESS_TIME)
            {
#ifdef __SERIAL_DEBUG
                Serial.println("SHORT PRESS");
                //                delay(SOFT_SHUTDOWN_PULSE);
                digitalWrite(PIN_SOFT_SHUTDOWN, HIGH);
                delay(SOFT_SHUTDOWN_PULSE);
                digitalWrite(PIN_SOFT_SHUTDOWN, LOW);
#else
                digitalWrite(PIN_SOFT_SHUTDOWN, HIGH);
                delay(SOFT_SHUTDOWN_PULSE);
                digitalWrite(PIN_SOFT_SHUTDOWN, LOW);
#endif
            }
        }
    }
*/
    prevBtnState = btnState;
    prevHoldingTime = holdingTime;
}

//////////////////////////////////////////////////////////////////////////////////////////////////////////////
// function : setup SPI_2 ; slave ; Rx only

void setup_SPI_2()
{
    SPI_2.setModule(2); // STM32F103C8 : low density 1 or 2
    SPISettings spiSettings(0, MSBFIRST, SPI_MODE0, DATA_SIZE_8BIT);  // 0 Hz : set by master
    SPI_2.beginTransactionSlave(spiSettings);
    spi_rx_reg(SPI_2.dev()); // Clear Rx register in case we already received SPI data
}

//////////////////////////////////////////////////////////////////////////////////////////////////////////////
// function : setup SPI_1 ; slave, Rx only

void setup_SPI_1()
{
    SPI_1.setModule(1); // STM32F103C8 : low density 1 or 2
    SPISettings spiSettings(0, MSBFIRST, SPI_MODE0, DATA_SIZE_8BIT); // 0 Hz : set by master
    SPI_1.beginTransactionSlave(spiSettings);
}

//////////////////////////////////////////////////////////////////////////////////////////////////////////////
// function : setup SPI_2 DMA ; Rx (MOSI) only

void setup_SPI_2_DMA()
{
    dma_init(DMA1);

    int ret_rx = dma_tube_cfg(DMA1, SPI_2_RX_DMA_CH, &SPI_2_DMA_RxTubeCfg);

    if (ret_rx != DMA_TUBE_CFG_SUCCESS)
    {
        // if the tube creation failed, no hope the code will work !
        while (1)
        {
#ifdef __SERIAL_DEBUG
            Serial.print("setup SPI_2 Rx DMA configuration error: ");
            Serial.println(ret_rx, HEX);
            Serial.println("Reset is needed!");
            delay(100);
#else
            // hope it will trigger the watchdog...
#endif
        }
    }

    spi_rx_reg(SPI_2.dev()); // Clear RX register in case we already received SPI data
    dma_attach_interrupt(DMA1, SPI_2_RX_DMA_CH, SPI_2_DMA_IRQ); // Attach interrupt to catch end of DMA transfer
    dma_enable(DMA1, SPI_2_RX_DMA_CH); // Rx : Enable DMA configurations
    spi_rx_dma_enable(SPI_2.dev()); // SPI DMA requests for Rx 
}

//////////////////////////////////////////////////////////////////////////////////////////////////////////////
// function : setup SPI_1 DMA ; Tx (MISO) only
// http://stm32duinoforum.com/forum/viewtopic_f_14_t_3527_start_10.html

void setup_SPI_1_DMA()
{
    dma_init(DMA1);

    int ret_tx = dma_tube_cfg(DMA1, SPI_1_TX_DMA_CH, &SPI_1_DMA_TxTubeCfg);

    if (ret_tx != DMA_TUBE_CFG_SUCCESS)
    {
        // if the tube creation failed, no hope the code will work !
        while (1)
        {
#ifdef __SERIAL_DEBUG
            Serial.print("setup SPI_1 Tx DMA configuration error: ");
            Serial.println(ret_tx, HEX);
            Serial.println("Reset is needed!");
            delay(100);
#else
            // hope it will trigger the watchdog...
#endif
        }
    }

    dma_enable(DMA1, SPI_1_TX_DMA_CH); // Tx : Enable DMA configurations
    spi_tx_dma_enable(SPI_1.dev()); // SPI DMA requests for Tx 
}

//////////////////////////////////////////////////////////////////////////////////////////////////////////////
// function : SPI_2 Rx IRQ

void SPI_2_DMA_IRQ()
{
    dma_irq_cause cause = dma_get_irq_cause(DMA1, SPI_2_RX_DMA_CH);

#ifdef __SERIAL_DEBUG
    switch (cause)
    {
    case DMA_TRANSFER_COMPLETE:            // Transfer is complete
        SPI_2_DMA_transfer_complete = true;
        //Serial.println("DMA_2 : DMA_TRANSFER_COMPLETE");
        break;
    case DMA_TRANSFER_ERROR:            // Error occurred during transfer
        Serial.println("DMA_2 : DMA_TRANSFER_ERROR");
        SPI_2_DMA_error = true;
        break;
    case DMA_TRANSFER_DME_ERROR:        // Direct mode error occurred during transfer
        Serial.println("DMA_2 : DMA_TRANSFER_DME_ERROR");
        SPI_2_DMA_error = true;
        break;
    case DMA_TRANSFER_FIFO_ERROR:        // FIFO error occurred during transfer
        Serial.println("DMA_2 : DMA_TRANSFER_FIFO_ERROR");
        SPI_2_DMA_error = true;
        break;
    case DMA_TRANSFER_HALF_COMPLETE:    // Transfer is half complete
        Serial.println("DMA_2 : DMA_TRANSFER_HALF_COMPLETE");
        SPI_2_DMA_error = true;
        break;
    default:
        Serial.println("DMA_2 : UNKNOWN ERROR");
        SPI_2_DMA_error = true;
        break;
    }
#else
    if (cause == DMA_TRANSFER_COMPLETE)
        SPI_2_DMA_transfer_complete = true;
    else
        SPI_2_DMA_error = true;
#endif

    dma_clear_isr_bits(DMA1, SPI_2_RX_DMA_CH);
}

//////////////////////////////////////////////////////////////////////////////////////////////////////////////
// function : copies the SPI/DMA buffer to bmpOut, stripping the command bytes ; duration  30µs

bool stripCmdBytes()
{
    for (int i = 0; i < OLED_PAGE_COUNT; i++)
    {
        uint8_t* pRxBuf = (uint8_t*)SPI_2_Rx_Buffer + i * OLED_SPI_PAGE_SIZE;
        uint16_t cmd = *(uint16_t*)pRxBuf; // command bytes
        uint8_t pageNum = *(uint8_t*)(pRxBuf + 2);

        // test 1st 3 bytes (= command bytes) of each frame ; 0x10 0x00 0xBn , n = frame #
        // shouldn't happen, see /CS ISR...
        if (cmd != 0x10 || pageNum != i + 0xB0)
        {
#ifdef __SERIAL_DEBUG
            Serial.println("stripCmdBytes() : ERROR");
#endif
            return false; // error, not in sync, etc.
        }

        // copy pages to bmpOled, drop command bytes
        memcpy((uint8_t*)&bmpOled + i * OLED_PAGE_SIZE, pRxBuf + OLED_CMD_SIZE, OLED_PAGE_SIZE);
    }

    return true;
}

//////////////////////////////////////////////////////////////////////////////////////////////////////////////
// function : converts the OLED bitmap into bmpOut bitmap
//
//    SSD1306/SSD1309/SSH1106 : 8 pages with 128 8bit vertical macropixels
//    bmpOut : 1024 8bit monochrome macropixels (128 lines 64 columns)
//    The operation is similar to a matrix transposition, each elementaty matrix being 8x8
//    duration : 3.9ms

void bmpOledToBmpOut()
{
    uint16_t i = 0; // bytes counter for output bitmap
    uint16_t j = 0; // bits counter for the current byte

    for (uint8_t page = 0; page < OLED_PAGE_COUNT; page++)
        for (uint8_t line = 0; line < OLED_LINES_PER_PAGE; line++)
            for (uint8_t col = 0; col < OLED_PAGE_SIZE; col++)
            {
                // vertical byte to horizontal byte

                uint8_t val = bmpOled[page][col];

                if (val & (1 << line))
                    bmpOut[i] |= (1 << (7 - j));
                else
                    bmpOut[i] &= ~(1 << (7 - j));


                if (val & (1 << line))
                    bmpOut[i] |= (1 << (7 - j));
                else
                    bmpOut[i] &= ~(1 << (7 - j));

                j++;
                j %= 8;

                if (j == 0) // byte complete
                    i++; // next byte
            }
}

// END
